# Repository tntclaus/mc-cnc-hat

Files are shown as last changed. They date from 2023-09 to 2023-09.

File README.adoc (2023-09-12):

= Makers' Comrade CNC HAT

Модели шилдов, которые превращают Raspberry в много-осевой ЧПУ с высокой производительностью.

Поддерживаются Raspberry Pi 3B, 3B+, 4 и другие микрокомпьютеры семейства Pi, с колодкой имеющей 40 gpio  (например, Orange Pi 3B).

== Модели

// === 5-осевой шилд
//
// //TODO:
//
// С независимыми UART линиями, в первую очередь для TMC2208, TMC2209 или для DRV8820, A4988 — обычный режим с конфигурацией через перемычки MS1,MS2,MS3 и других драйвера, поддерживающие DIR/STEP.
//
// xref:kicad/mc_cnc_hat_x5/README.adoc[]
//

=== 7-осевой шилд с CAN bus

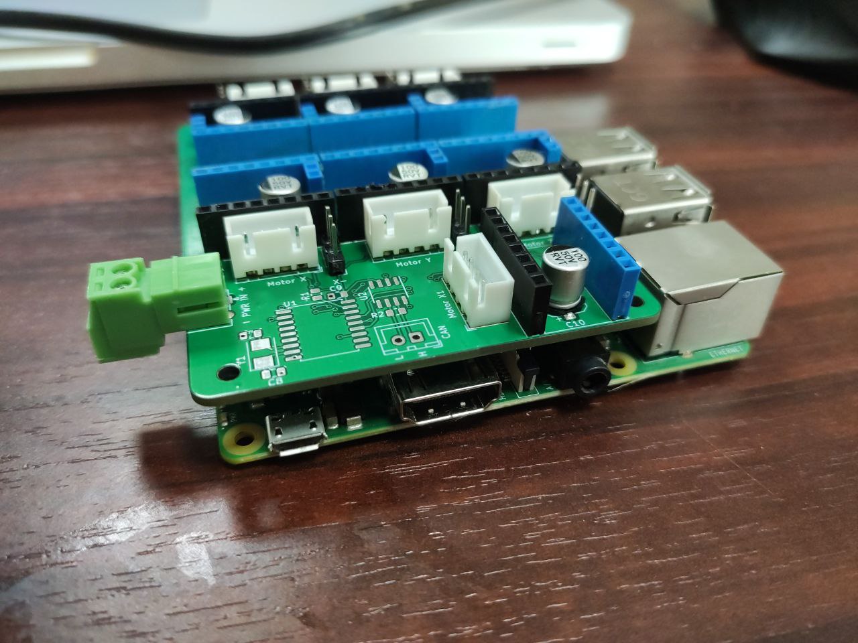
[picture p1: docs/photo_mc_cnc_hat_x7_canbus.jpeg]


Шилд для управления 7 двигателями ЧПУ и CAN bus периферией для Raspberry Pi 3B/3B+/4B и Orange Pi 3B (не проверялось, но должно работать).

xref:kicad/mc_cnc_hat_x7_canbus/README.adoc[]

=== 8-осевой шилд

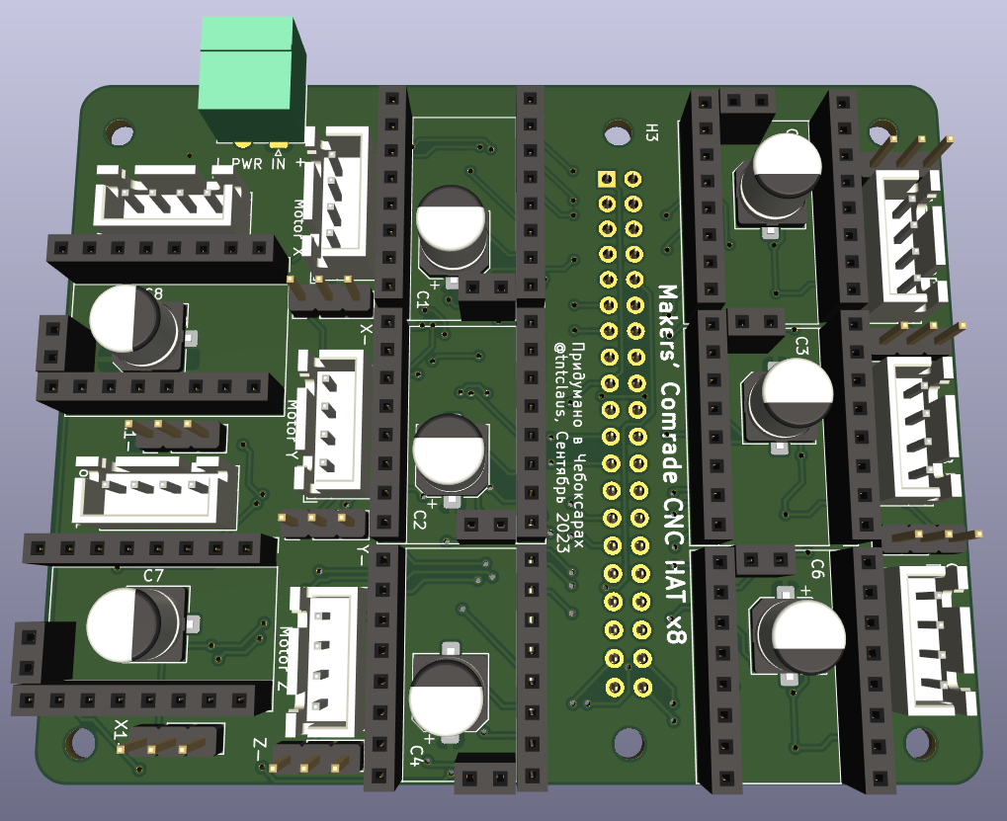
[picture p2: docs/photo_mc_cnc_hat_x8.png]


С двумя общими UART линиями для драйверов TMC2209 или для DRV8820, A4988 — обычный режим с конфигурацией через перемычки MS1,MS2,MS3 и других драйвера, поддерживающие DIR/STEP.

xref:kicad/mc_cnc_hat_x7_canbus/README.adoc[]

== Общие для всех моделей возможности

* Одновременное управление 5-7 драйверами шаговых двигателей:
** Поддерживаемые драйвера:
*** TMC2209, TMC2208 — режим UART с указанием адреса через перемычки MS1/MS2;
*** DRV8820, A4988 — обычный режим с конфигурацией через перемычки MS1,MS2,MS3;
*** Любые другие драйвера, поддерживающие DIR/STEP.
* Суммарная пиковая производительность всех двигателей 1018 тыс. шагов/секунду (Klipper с патчем, Linux CNC не тестировался, но вероятно будет результат того же порядка).
* Поддержка концевиков для осей X, Y, Z, A, B, C как стандартного типа, так и DIAG выходов для безсенсорной парковки драйвера TMC2209.
* Поддержка дополнительного концевика (например, для датчика наличия/движения филамента 3д принтера).
* Поддерживаемые системы: Linux CNC (не тестировалось), Klipper.

== Инструкция по установке

Инструкция тут: xref:docs/klipper.adoc[]

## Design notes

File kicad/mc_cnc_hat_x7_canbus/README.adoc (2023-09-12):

= Makers' Comrade CNC Hat x7 (CAN bus)



Шилд для управления 7 двигателями ЧПУ и CAN bus периферией для Raspberry Pi 3B/3B+/4B и Orange Pi 3B (не проверялось, но должно работать).

С двумя общими UART линиями для драйверов TMC2209 или для DRV8820, A4988 — обычный режим с конфигурацией через перемычки MS1,MS2,MS3 и других драйвера, поддерживающие DIR/STEP.

TMC2208 можно установить по 1 на каждую UART линию, при условии что на остальных местах будут драйвера не требующие использования UART (например, DRV8820).

Первая UART линия общая для X, X1, Y, Z.
Вторая UART линия общая для A, B, C.

== Возможности

* Одновременное управление 7 драйверами шаговых двигателей. Поддерживаемые драйвера:
** TMC2209, TMC2208 — режим UART с указанием адреса через перемычки MS1/MS2;
** DRV8820, A4988 — обычный режим с конфигурацией через перемычки MS1,MS2,MS3;
** Любые другие драйвера, поддерживающие DIR/STEP.
* Суммарная пиковая производительность всех двигателей 1018 тыс. шагов/секунду на RPi 3B+ (Klipper из форка https://github.com/tntclaus/klipper[tntclaus/klipper], Linux CNC не тестировался, но вероятно будет результат того же порядка).
* Поддержка концевиков для осей X, Y, Z, A, B, C как стандартного типа, так и DIAG выходов для без сенсорной парковки драйвера TMC2209.
* Поддержка дополнительного концевика (например, для датчика наличия/движения филамента 3д принтера).
* CANBUS host на базе MCP2515 и трансивера SN65HVD230:
** Даёт возможность гибкого дополнения станка периферией:
*** С контроллером экструдера https://github.com/makerbase-mks/MKS-THR36-THR42-UTC[MKS THR36] можно использовать как 3d принтер (не помешает дополнительный контроллер нагревательного стола/камеры).
*** С CAN контроллером шпинделя можно использовать как ЧПУ фрезер.
*** ...и т.д.
* Поддерживаемые системы: Linux CNC (не тестировалось), Klipper.

== Использование

Для использования с Klipper см. инструкцию xref:../../docs/klipper.adoc[по настройке Klipper]

Конфигурирование драйверов описано в  xref:../../docs/drivers_x7_x8.adoc[инструкции].

== Пины

.Моторы
|===
|Назначение |Motor X |Motor X1 |Motor Y |Motor Z |Motor A |Motor B |Motor C

|STEP
|GPIO3
|GPIO6
|GPIO27
|GPIO19
|GPIO23
|GPIO1
|GPIO20

|DIR
|GPIO2
|GPIO15
|GPIO17
|GPIO13
|GPIO24
|GPIO12
|GPIO21

|UART
|GPIO5
|GPIO5
|GPIO5
|GPIO5
|GPIO25
|GPIO25
|GPIO25

|DIAG/Endstop
|GPIO4
|N/A
|GPIO0
|GPIO26
|GPIO18
|GPIO7
|GPIO16
|===

.CAN bus
|===
|Назначение |GPIO
|CS
|GPIO8

|MOSI
|GPIO10

|MISO
|GPIO9

|SCK
|GPIO11
|===

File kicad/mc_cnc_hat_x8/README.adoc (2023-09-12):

= Makers' Comrade CNC Hat (x8 drivers)



Шилд для управления 8 двигателями ЧПУ для Raspberry Pi 3B/3B+/4B и Orange Pi 3B (не проверялось, но должно работать).

С двумя общими UART линиями для драйверов TMC2209 или для DRV8820, A4988 — обычный режим с конфигурацией через перемычки MS1,MS2,MS3 и других драйвера, поддерживающие DIR/STEP.

TMC2208 можно установить по 1 на каждую UART линию, при условии что на остальных местах будут драйвера не требующие использования UART (например, DRV8820).

Первая UART линия общая для X, X1, Y, Z.
Вторая UART линия общая для A, A1, B, C.

== Возможности

* Одновременное управление 8 драйверами шаговых двигателей. Поддерживаемые драйвера:
** TMC2209 — режим UART с указанием адреса через перемычки MS1/MS2;
** TMC2208, DRV8820, A4988 — обычный режим с конфигурацией через перемычки MS1,MS2,MS3;
** Любые другие драйвера, поддерживающие DIR/STEP.
* Суммарная пиковая производительность всех двигателей 1018 тыс. шагов/секунду на RPi 3B+ (Klipper из форка https://github.com/tntclaus/klipper[tntclaus/klipper], Linux CNC не тестировался, но вероятно будет результат того же порядка).
* Поддержка концевиков для всех двигателей — как стандартного типа, так и DIAG выходов для безсенсорной парковки драйвера TMC2209.
* Поддерживаемые системы: Linux CNC (не тестировалось), Klipper.

== Использование

Для использования с Klipper см. инструкцию xref:../../docs/klipper.adoc[по настройке Klipper]

Конфигурирование драйверов описано в  xref:../../docs/drivers_x7_x8.adoc[инструкции].

== Пины

.Моторы
|===
|Назначение |Motor X |Motor X1 |Motor Y |Motor Z |Motor A |Motor A1 |Motor B |Motor C

|STEP
|GPIO3
|GPIO6
|GPIO27
|GPIO19
|GPIO23
|GPIO9
|GPIO1
|GPIO20

|DIR
|GPIO2
|GPIO15
|GPIO17
|GPIO13
|GPIO24
|GPIO10
|GPIO12
|GPIO21

|UART
|GPIO5
|GPIO5
|GPIO5
|GPIO5
|GPIO25
|GPIO25
|GPIO25
|GPIO25

|DIAG/Endstop
|GPIO4
|GPIO11
|GPIO0
|GPIO26
|GPIO18
|GPIO8
|GPIO7
|GPIO16
|===

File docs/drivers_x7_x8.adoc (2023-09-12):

= Настройка драйверов

Каждый драйвер имеет паяемые перемычки MS1/MS2/MS3 для конфигурирования драйвера мотора:

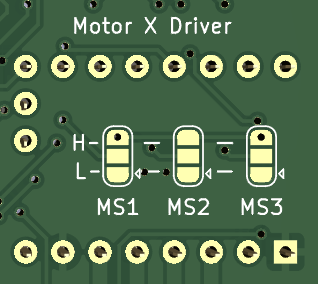
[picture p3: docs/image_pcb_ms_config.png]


* Если запаять H (3.3V) и центр — будет логическая единица
* Если запаять L (GND) и центр — будет логический ноль

WARNING: Если соединить H и L — будет короткое замыкание. Лучше так не делать.

Они аналогичны джамперам на RAMPS и позволяют в случае с TMC2208 (в режиме без UART) DRV8820, A4988 и аналогичными — задавать микрошаг двигателя.

Для TMC2209 они позволяют задать адрес на линии UART.

Для TMC2208 в режиме UART они бесполезны.

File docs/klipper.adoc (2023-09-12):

== Использование с Klipper

Установку лучше всего делать с помощью установщика https://github.com/dw-0/kiauh[KIAUH].

Для максимальной производительности надо заменить установленный с помощью KIAUH klipper на форк из https://github.com/tntclaus/klipper[tntclaus/klipper] с поддержкой аппаратного ускорения gpio на RPi. Если установить из основного репозитория, gpio будет очень медленным и использовать все преимущества контроллеров не выйдет.

.Команды для замены репозитория на форк
[source]
----
# Выполнять от пользователя pi
cd ~
rm -Rf klipper
git clone -b work-linux-rpi-gpio-20210419 --single-branch git@github.com:tntclaus/klipper.git
----

Далее установка и сборка mcu Klipper делается по https://www.klipper3d.org/RPi_microcontroller.html[стандартной процедуре].

NOTE: В меню конфигурации, при вызове `make menuconfig` надо выбрать тип "Microcontroller Architecture" — "Linux Process", затем выбрать модель Raspberry.

Кроме того, надо в `/boot/cmdline.txt` распберри дописать в конце строки `isolcpus=3` — это запретит линуксу назначать на ядро под номером три какие-либо процессы, кроме тех, для которых оно задано явным образом в стартовом скрипте. Данное ядро будет использоваться процессом `klipper_mcu`.

NOTE: WiFi на Raspberry использовать нельзя, так как это может приводить к блокированию процесса `klipper_mcu` и сбоям при работе станка.

После установки требуется сконфигурировать klipper так, чтобы он мог работать с драйверами шаговых двигателей. Описание того какие gpio за что отвечают есть на страницах соответствующих моделей шилдов.

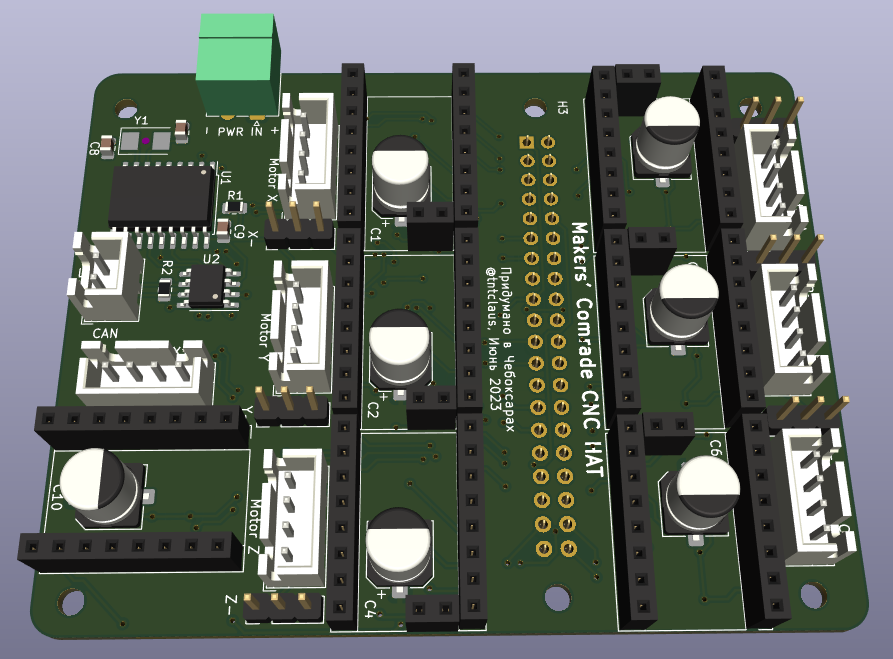
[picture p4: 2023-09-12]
docs/pcb_3d.png

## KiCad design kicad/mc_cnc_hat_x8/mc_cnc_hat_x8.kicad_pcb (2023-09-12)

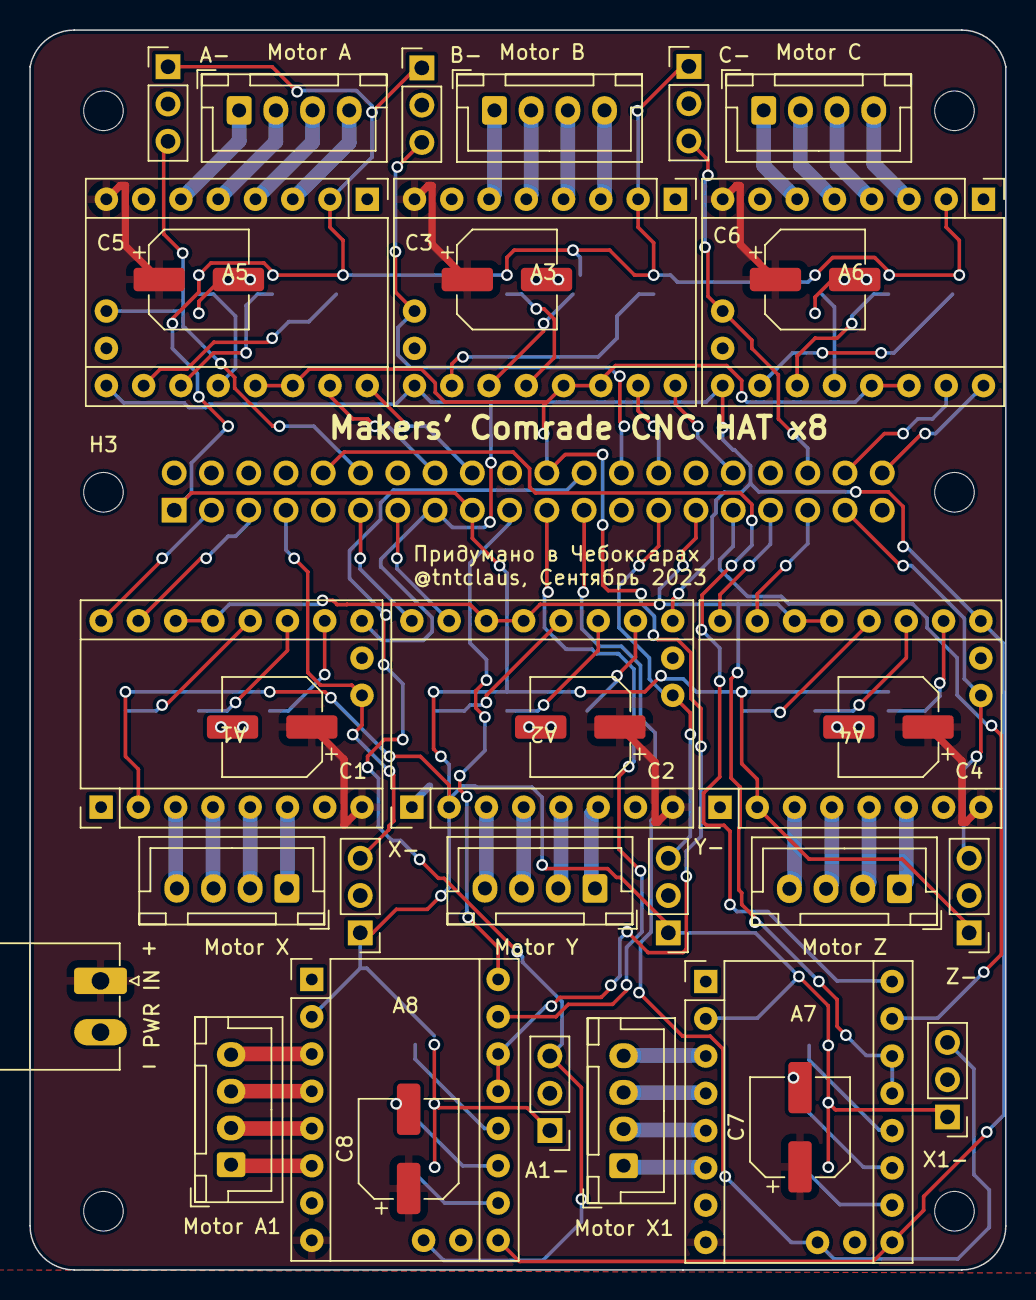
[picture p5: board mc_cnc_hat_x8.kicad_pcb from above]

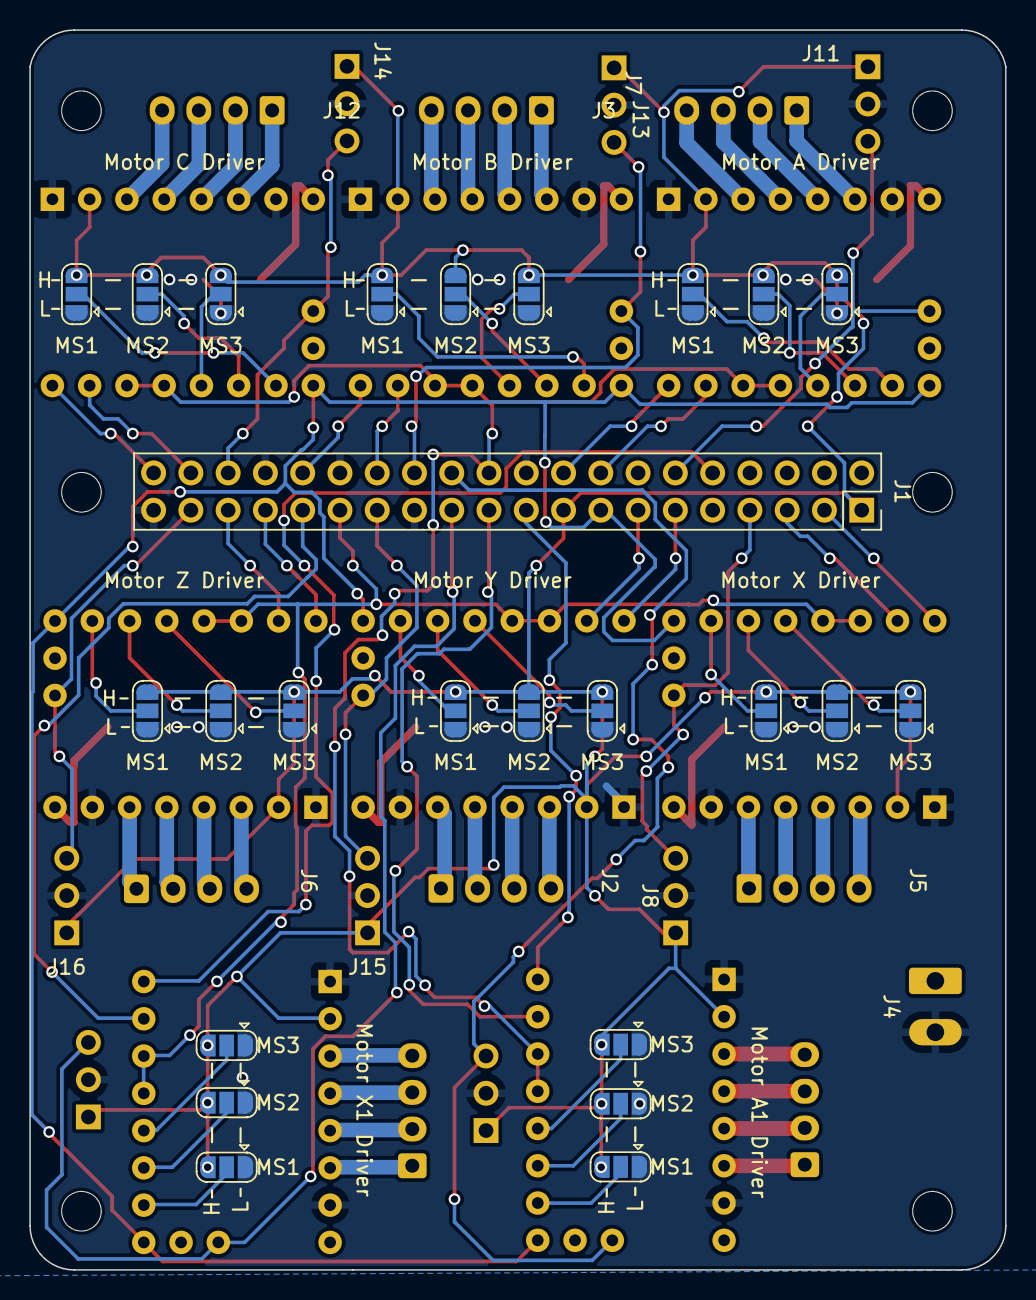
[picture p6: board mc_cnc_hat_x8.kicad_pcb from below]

Board: 2 copper layers, 66.5 x 84.5 mm, 64 parts (25 on the bottom side), 86 nets.

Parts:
A1: Motor X Driver; TMC220X
A2: Motor Y Driver; TMC220X
A3: Motor B Driver; TMC220X
A4: Motor Z Driver; TMC220X
A5: Motor A Driver; TMC220X
A6: Motor C Driver; TMC220X
A7: Motor X1 Driver; TMC220X
A8: Motor A1 Driver; TMC220X
C1, C2, C3, C4, C5, C6, C7, C8: 100µF 50V; CP_Elec_6.3x7.7
H1, H2, H3, H4, H5, H6: MountingHole; MountingHole_2.7mm_M2.5_ISO14580
J1: Raspberry_Pi_2_3; PinSocket_2x20_P2.54mm_Vertical
J2: Motor Y; JST_XH_B4B-XH-A_1x04_P2.50mm_Vertical
J3: Motor B; JST_XH_B4B-XH-A_1x04_P2.50mm_Vertical
J4: PWR IN; PhoenixContact_MC_1,5_2-G-3.5_1x02_P3.50mm_Horizontal
J5: Motor X; JST_XH_B4B-XH-A_1x04_P2.50mm_Vertical
J6: Motor Z; JST_XH_B4B-XH-A_1x04_P2.50mm_Vertical
J7: Motor A; JST_XH_B4B-XH-A_1x04_P2.50mm_Vertical
J8: X-; PinHeader_1x03_P2.54mm_Vertical
J9: X1-; PinHeader_1x03_P2.54mm_Vertical
J10: A1-; PinHeader_1x03_P2.54mm_Vertical
J11: A-; PinHeader_1x03_P2.54mm_Vertical
J12: Motor C; JST_XH_B4B-XH-A_1x04_P2.50mm_Vertical
J13: B-; PinHeader_1x03_P2.54mm_Vertical
J14: C-; PinHeader_1x03_P2.54mm_Vertical
J15: Y-; PinHeader_1x03_P2.54mm_Vertical
J16: Z-; PinHeader_1x03_P2.54mm_Vertical
J17: Motor X1; JST_XH_B4B-XH-A_1x04_P2.50mm_Vertical
J18: Motor A1; JST_XH_B4B-XH-A_1x04_P2.50mm_Vertical
JP1, JP4, JP7, JP10, JP13, JP16, JP19, JP22: MS3; SolderJumper-3_P1.3mm_Open_RoundedPad1.0x1.5mm
JP2, JP5, JP8, JP11, JP14, JP17, JP20, JP23: MS2; SolderJumper-3_P1.3mm_Open_RoundedPad1.0x1.5mm
JP3, JP6, JP9, JP12, JP15, JP18, JP21, JP24: MS1; SolderJumper-3_P1.3mm_Open_RoundedPad1.0x1.5mm

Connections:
+3V3: A1.2 (VDD), A2.2 (VDD), A3.2 (VDD), A4.2 (VDD), A5.2 (VDD), A6.2 (VDD), A7.2 (VDD), A8.2 (VDD), J1.1 (3V3), J1.17 (3V3), J8.1, J9.1, J10.1, J11.1, J13.1, J14.1, J15.1, J16.1, JP1.3 (B), JP2.3 (B), JP3.3 (B), JP4.3 (B), JP5.3 (B), JP6.3 (B), JP7.3 (B), JP8.3 (B), JP9.3 (B), JP10.3 (B), JP11.3 (B), JP12.3 (B), JP13.3 (B), JP14.3 (B), JP15.3 (B), JP16.3 (B), JP17.3 (B), JP18.3 (B), JP19.3 (B), JP20.3 (B), JP21.3 (B), JP22.3 (B), JP23.3 (B), JP24.3 (B)
/MA1 DIAG: A8.18 (DIAG), J1.24 (~CE0/GPIO8), J10.3
/MA1 DIR: A8.16 (DIR), J1.19 (MOSI0/GPIO10)
/MA1 STEP: A8.15 (STEP), J1.21 (MISO0/GPIO9)
/MA DIAG: A5.18 (DIAG), J1.12 (GPIO18/PWM0), J11.3
/MA DIR: A5.16 (DIR), J1.18 (GPIO24)
/MA STEP: A5.15 (STEP), J1.16 (GPIO23)
/MB DIAG: A3.18 (DIAG), J1.26 (~CE1/GPIO7), J13.3
/MB DIR: A3.16 (DIR), J1.32 (PWM0/GPIO12)
/MB STEP: A3.15 (STEP), J1.28 (ID_SC/GPIO1)
/MC DIAG: A6.18 (DIAG), J1.36 (GPIO16), J14.3
/MC DIR: A6.16 (DIR), J1.40 (GPIO21/SCLK1)
/MC STEP: A6.15 (STEP), J1.38 (GPIO20/MOSI1)
/MX1 DIAG: A7.18 (DIAG), J1.23 (SCLK0/GPIO11), J9.3
/MX1 DIR: A7.16 (DIR), J1.10 (GPIO15/RXD)
/MX1 STEP: A7.15 (STEP), J1.31 (GCLK2/GPIO6)
/MX DIAG: A1.18 (DIAG), J1.7 (GCLK0/GPIO4), J8.3
/MX DIR: A1.16 (DIR), J1.3 (SDA/GPIO2)
/MX STEP: A1.15 (STEP), J1.5 (SCL/GPIO3)
/MY DIAG: A2.18 (DIAG), J1.27 (ID_SD/GPIO0), J15.3
/MY DIR: A2.16 (DIR), J1.11 (GPIO17)
/MY STEP: A2.15 (STEP), J1.13 (GPIO27)
/MZ DIAG: A4.18 (DIAG), J1.37 (GPIO26), J16.3
/MZ DIR: A4.16 (DIR), J1.33 (PWM1/GPIO13)
/MZ STEP: A4.15 (STEP), J1.35 (GPIO19/MISO1)
/Motor A1/1A: A8.4 (1A), J18.3
/Motor A1/1B: A8.3 (1B), J18.4
/Motor A1/2A: A8.5 (2A), J18.2
/Motor A1/2B: A8.6 (2B), J18.1
/Motor A1/MS1: A8.10 (MS1), JP24.2 (C)
/Motor A1/MS2: A8.11 (MS2), JP23.2 (C)
/Motor A1/MS3: A8.12 (NC/TX), JP22.2 (C)
/Motor A/1A: A5.4 (1A), J7.3
/Motor A/1B: A5.3 (1B), J7.4
/Motor A/2A: A5.5 (2A), J7.2
/Motor A/2B: A5.6 (2B), J7.1
/Motor A/MS1: A5.10 (MS1), JP15.2 (C)
/Motor A/MS2: A5.11 (MS2), JP14.2 (C)
/Motor A/MS3: A5.12 (NC/TX), JP13.2 (C)
/Motor B/1A: A3.4 (1A), J3.3
/Motor B/1B: A3.3 (1B), J3.4
/Motor B/2A: A3.5 (2A), J3.2
/Motor B/2B: A3.6 (2B), J3.1
/Motor B/MS1: A3.10 (MS1), JP9.2 (C)
/Motor B/MS2: A3.11 (MS2), JP8.2 (C)
/Motor B/MS3: A3.12 (NC/TX), JP7.2 (C)
/Motor C/1A: A6.4 (1A), J12.3
/Motor C/1B: A6.3 (1B), J12.4
/Motor C/2A: A6.5 (2A), J12.2
/Motor C/2B: A6.6 (2B), J12.1
/Motor C/MS1: A6.10 (MS1), JP18.2 (C)
/Motor C/MS2: A6.11 (MS2), JP17.2 (C)
/Motor C/MS3: A6.12 (NC/TX), JP16.2 (C)
/Motor X1/1A: A7.4 (1A), J17.3
/Motor X1/1B: A7.3 (1B), J17.4
/Motor X1/2A: A7.5 (2A), J17.2
/Motor X1/2B: A7.6 (2B), J17.1
/Motor X1/MS1: A7.10 (MS1), JP21.2 (C)
/Motor X1/MS2: A7.11 (MS2), JP20.2 (C)
/Motor X1/MS3: A7.12 (NC/TX), JP19.2 (C)
/Motor X/1A: A1.4 (1A), J5.3
/Motor X/1B: A1.3 (1B), J5.4
/Motor X/2A: A1.5 (2A), J5.2
/Motor X/2B: A1.6 (2B), J5.1
/Motor X/MS1: A1.10 (MS1), JP3.2 (C)
/Motor X/MS2: A1.11 (MS2), JP2.2 (C)
/Motor X/MS3: A1.12 (NC/TX), JP1.2 (C)
/Motor Y/1A: A2.4 (1A), J2.3
/Motor Y/1B: A2.3 (1B), J2.4
/Motor Y/2A: A2.5 (2A), J2.2
/Motor Y/2B: A2.6 (2B), J2.1
/Motor Y/MS1: A2.10 (MS1), JP6.2 (C)
/Motor Y/MS2: A2.11 (MS2), JP5.2 (C)
/Motor Y/MS3: A2.12 (NC/TX), JP4.2 (C)
/Motor Z/1A: A4.4 (1A), J6.3
/Motor Z/1B: A4.3 (1B), J6.4
/Motor Z/2A: A4.5 (2A), J6.2
/Motor Z/2B: A4.6 (2B), J6.1
/Motor Z/MS1: A4.10 (MS1), JP12.2 (C)
/Motor Z/MS2: A4.11 (MS2), JP11.2 (C)
/Motor Z/MS3: A4.12 (NC/TX), JP10.2 (C)
/UART_A: A3.13 (PDN/RX), A3.14 (NC/CLK), A5.13 (PDN/RX), A5.14 (NC/CLK), A6.13 (PDN/RX), A6.14 (NC/CLK), A8.13 (PDN/RX), A8.14 (NC/CLK), J1.22 (GPIO25)
/UART_X: A1.13 (PDN/RX), A1.14 (NC/CLK), A2.13 (PDN/RX), A2.14 (NC/CLK), A4.13 (PDN/RX), A4.14 (NC/CLK), A7.13 (PDN/RX), A7.14 (NC/CLK), J1.29 (GCLK1/GPIO5)
GND: A1.1 (GND), A1.7 (GND), A2.1 (GND), A2.7 (GND), A3.1 (GND), A3.7 (GND), A4.1 (GND), A4.7 (GND), A5.1 (GND), A5.7 (GND), A6.1 (GND), A6.7 (GND), A7.1 (GND), A7.7 (GND), A8.1 (GND), A8.7 (GND), C1.2, C2.2, C3.2, C4.2, C5.2, C6.2, C7.2, C8.2, J1.20 (GND), J1.25 (GND), J1.30 (GND), J1.34 (GND), J1.39 (GND), J4.2, J8.2, J9.2, J10.2, J11.2, J13.2, J14.2, J15.2, J16.2, JP1.1 (A), JP2.1 (A), JP3.1 (A), JP4.1 (A), JP5.1 (A), JP6.1 (A), JP7.1 (A), JP8.1 (A), JP9.1 (A), JP10.1 (A), JP11.1 (A), JP12.1 (A), JP13.1 (A), JP14.1 (A), JP15.1 (A), JP16.1 (A), JP17.1 (A), JP18.1 (A), JP19.1 (A), JP20.1 (A), JP21.1 (A), JP22.1 (A), JP23.1 (A), JP24.1 (A)
MEN: A1.9 (~ENABLE), A2.9 (~ENABLE), A3.9 (~ENABLE), A4.9 (~ENABLE), A5.9 (~ENABLE), A6.9 (~ENABLE), A7.9 (~ENABLE), A8.9 (~ENABLE), J1.15 (GPIO22)
Vin: A1.8 (VMOT), A2.8 (VMOT), A3.8 (VMOT), A4.8 (VMOT), A5.8 (VMOT), A6.8 (VMOT), A7.8 (VMOT), A8.8 (VMOT), C1.1, C2.1, C3.1, C4.1, C5.1, C6.1, C7.1, C8.1, J4.1

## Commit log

2023-09-12 initial commit with x7 can bus capable model
    [canbus.kicad_sch, mc_cnc_hat_x7_canbus.kicad_pcb, mc_cnc_hat_x7_canbus.kicad_sch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]
2023-09-12 GPIO pin map
2023-09-12 руководство по конфигурированию драйверов
2023-09-12 добавлена версия с 8 драйверами
    [canbus.kicad_sch, mc_cnc_hat_x8.kicad_pcb, mc_cnc_hat_x8.kicad_sch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]
